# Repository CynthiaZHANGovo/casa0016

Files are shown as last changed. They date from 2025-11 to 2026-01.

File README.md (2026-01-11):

# Study Assistant

The **Study Assistant** is a smart, sensor-driven desktop companion designed to improve study efficiency and encourage healthier learning habits. It monitors brightness, noise, distance, and user presence, then provides real-time feedback through an RGB LCD and multi-color LED indicators.

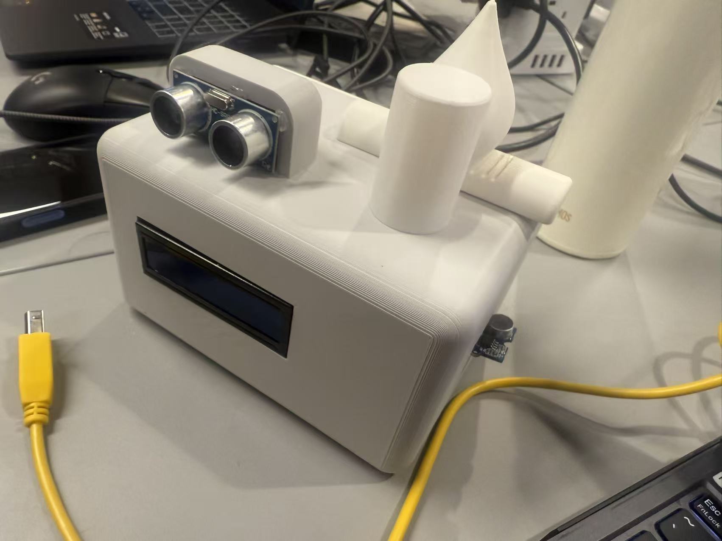
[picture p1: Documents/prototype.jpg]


---

## 📌 Overview

The Study Assistant integrates several sensors, a dynamic feedback system, and a custom 3D-printed enclosure. It automatically tracks focus time, recommends study durations, and enforces rest intervals based on environmental quality.

### Core Capabilities

* Real-time environmental monitoring (lux + noise)
* Ultrasonic-based presence and distance measurement
* Dynamic recommended study duration
* Dynamic rest duration
* Automatic environment light control
* Multi-state LED status feedback
* LCD dual-page interface
* Smart Rest Mode with power saving
* Refined behavior when distance is invalid (LEDs turn off unless noisy)

---

## ✨ Key Features

### 🎯 Smart Focus Tracking

* Detects when the user is present
* Measures:

  * Current study session duration
  * Total accumulated study time
* Continuously compares time against automatically calculated recommendations

### 😴 Intelligent Rest Mode

Triggered when continuous study exceeds recommended duration.

During Rest Mode:

* Status LEDs locked to **red**
* Environment LEDs **off**
* LCD shows:

  * `Rest: <elapsed> / <required> m`
  * `Leave desk...`
* After required rest time: system enters **Rest Finished** state

  * Status LEDs turn **orange** until the user returns

### 🔄 Updated LED Behavior

Latest logic:

* **Green** — user present & environment normal
* **Blue** — user too close
* **Yellow** — environment too noisy
* **Red** — rest required
* **Orange** — rest finished (waiting for user)
* **No Delay** — LED color now updates instantly
* **Invalid distance** — *LED stays off unless noise is high*

### 📟 LCD Dual-Page System

When not resting, the LCD alternates every 2 seconds:

**Page 0 — Study Progress**

```
Total: <minutes>
(<current> / Rec:<recommended>)
```

**Page 1 — Environment**

```
Lux: <value>
Noise: <value>
```

---

## 🧠 Sensor Logic Summary

| Sensor | Purpose | Usage |
| --- | --- | --- |
| HC-SR04 | Distance & presence | posture, presence, rest logic |
| VEML7700 | Brightness | environment quality, rest & study tuning, auto light control |
| Analog microphone | Noise | environment quality, LED feedback |
| millis() | Timing | non-blocking session & rest tracking |

Both study and rest durations adapt dynamically to environmental conditions.

---

# 🖼️ Design Documents (in `/Documents/`)

All design drawings, early concept sketches, electronics documentation, and PCB design files are stored in:

/Documents/

These materials illustrate the full development process from concept → electronic design → PCB layout.

---

## ✏️ Concept Sketch

The initial sketch visualizes the first idea of the Study Assistant, including enclosure proportion, sensor placement, and user-facing interactions.

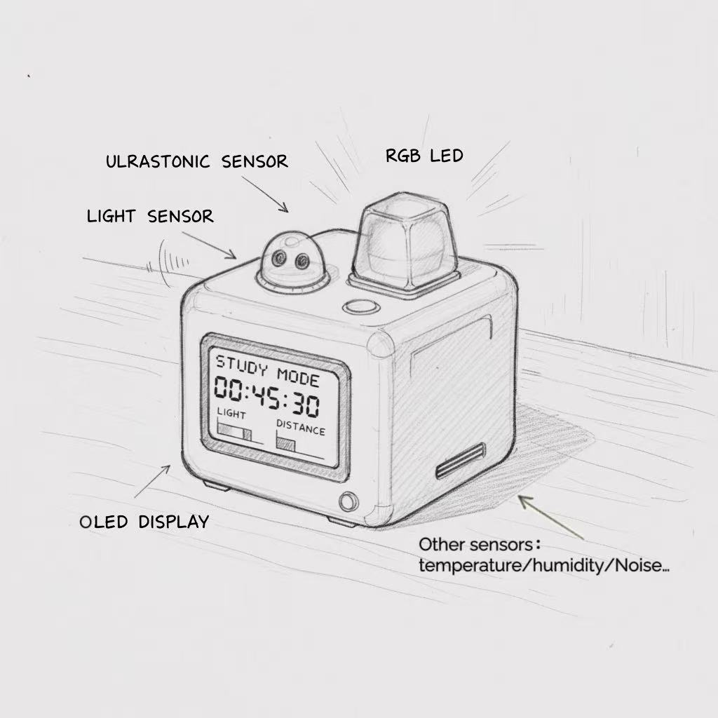
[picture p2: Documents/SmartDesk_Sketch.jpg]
Concept Sketch


---

## 🧩 Schematic Diagram

The schematic documents all circuit connections including the ultrasonic sensor, VEML7700 brightness sensor, microphone input, I2C LCD, and indicator LEDs.
**Designed in Tinkercad.**

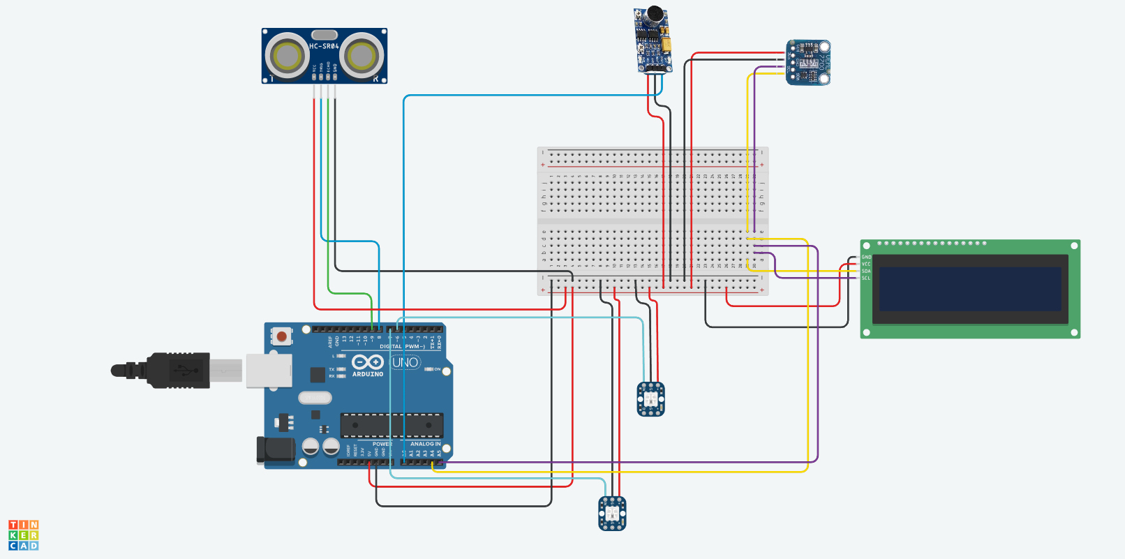
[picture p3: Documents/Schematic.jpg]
Schematic


---

## 🟩 PCB Layout

The PCB layout converts the schematic into a manufacturable and compact board designed to fit inside the 3D printed shell.
**Designed in Tinkercad.**

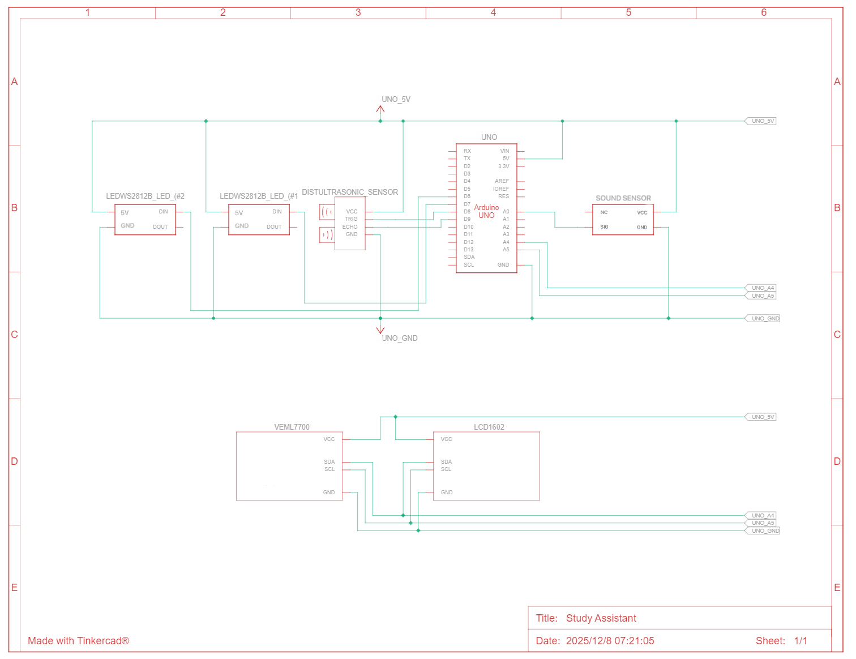
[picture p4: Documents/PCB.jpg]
PCB Layout


---

# 🛠️ 3D Printed Shell (from `/Shell/`)

The Study Assistant enclosure includes a main shell and a detachable top cover.  
Both parts were modelled for 3D printing through *Fusion 360* and designed to house all electronics securely.

---

### 🟦 Shell (Main Body)

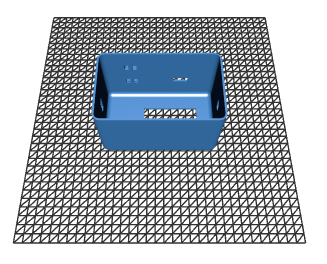
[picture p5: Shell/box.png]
Shell Front Placeholder


**STL download:**  
https://github.com/CynthiaZHANGovo/casa0016/blob/main/Shell/Studybox2.0.stl

---

### 🟧 Shell Cover

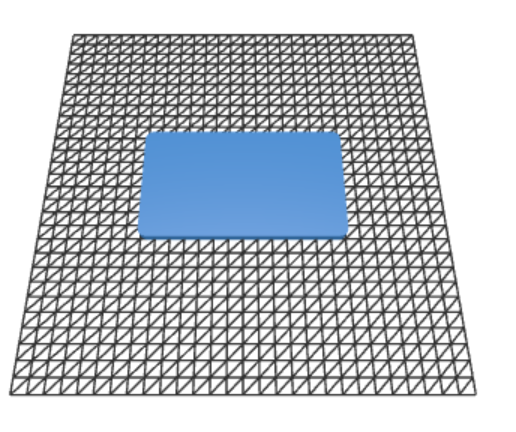
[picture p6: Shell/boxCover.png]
Shell Cover Placeholder


**STL download:**  
https://github.com/CynthiaZHANGovo/casa0016/blob/main/Shell/Study_Box_Cover.stl

---

### 🎃 Additional Decorative Models (Open-source Resources)

These optional decorative elements are sourced from open 3D model libraries and used for aesthetic enhancement:

- **Campfire decoration** — [open-source model](https://makerworld.com.cn/zh/models/672740-gou-huo-deng-mi-ni-ledgou-huo-tai-deng?from=search#profileId-617935)
- **Lamp shade decoration** — [open-source model](https://makerworld.com.cn/zh/models/1686858-fen-wei-deng?from=search#profileId-1854094)
- **Pumpkin lantern decoration** — [open-source model](https://makerworld.com.cn/zh/models/1678338-nan-gua-deng-zhao-zhi-xu-1xiao-shi-da-yin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)

---

## 🎬 Demo Videos

This section demonstrates the Study Assistant in real-world use, including both general functionality and dynamic mode switching behavior.

---

### ▶️ Demo 1 — Full Functionality Overview

Demonstrates the **overall workflow and core features** of the Study Assistant, including:

* Presence detection
* Study time tracking
* Environmental monitoring
* Noise warning
* Distance warning
* LCD dual-page display
* LED status feedback

📺 **Watch video:**
[https://www.youtube.com/watch?v=R-oBgMGgS7g](https://www.youtube.com/watch?v=R-oBgMGgS7g)

Full Function Demo (https://www.youtube.com/watch?v=R-oBgMGgS7g)

### ▶️ Demo 2 — Mode Switching & Status Transitions

Focuses on **different system modes and real-time transitions**, including:

* Normal study mode
* Rest mode activation
* Rest finished state

📺 **Watch video:**
[https://youtu.be/XXJL6YK80Yg](https://youtu.be/XXJL6YK80Yg)

Mode Switching Demo (https://youtu.be/XXJL6YK80Yg)

---

# 💻 Arduino Code (Final Version)

The complete Arduino sketch with all functions, detailed English comments, and structured serial output is located at:

/StudyAssistant

Direct link:  
👉 **[Study_Assistant_Final.ino](StudyAssistant)**

---

# 📂 Repository

Full project available at:  
👉 https://github.com/CynthiaZHANGovo/casa0016

---

# 👩‍💻 Author

**Xinyi Zhang**  Cyn Zhang

GitHub: https://github.com/CynthiaZHANGovo  
UCL CASA0016

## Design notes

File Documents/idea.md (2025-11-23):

# **"Focused Study Feedback Station"**

A small desk device for combined monitoring and adjustment of **time + environment** while you are studying at your desk (light & temperature adjustment, distance reminders, and smart break prompts).

---

### 1. Ultrasonic Distance Sensor

- Detects whether you are sitting at the desk, to record **effective study time**.

- Measures how far you are from the screen, to trigger **“too close” distance reminders**.

### 2. Light Sensor

- Measures ambient/desk brightness (you should at least have the light on when studying).

- When the environment is too dark, it can automatically turn on a lamp or remind you to switch it on.

### 3. (Optional) Noise + Temperature / Humidity

- **Noise**: checks whether the study environment is too noisy.

- **Temperature / Humidity**: checks if the room is too hot, cold, or stuffy.

- These act as additional indicators of overall environment quality.

---

### Logic

- The system only starts recording when it detects that **you are present** at the desk.

- It records your **daily effective study time** and, during those periods, logs the corresponding environment data.

- Based on brightness, temperature, noise level, and distance while you are seated, it produces an **environment quality feedback** for your study sessions.

---

### Real-time Display

- `Today’s focused time: X minutes`

- `Environment: brightness XX, temperature XX, noise XX (optional)`

- `Distance: XX cm (too close / OK)`

---

### Feedback Channels

- **OLED screen**: shows focused time, environment readings, and textual warnings or tips.

- **RGB LED**:

  - Green: you are present and the environment is generally OK.

  - Yellow: minor issues (slightly dark, slightly noisy, etc.).

  - Red: clear problems (too dark, too noisy, or too close to the screen).

---

### “Time to Take a Break” Reminder (Not Just Time-Based)

- The system does **not** trigger breaks based only on “you have sat for N minutes”.

- Instead, it combines:

  1.  You have been in a continuous focused session for a relatively long period (e.g. > 30–45 minutes), **and**

  2.  Your environment or posture starts to degrade:

      - brightness getting too low,

      - temperature drifting to an uncomfortable range,

      - noise level increasing, or

      - you are sitting increasingly close to the screen.

- Only when **“long enough focus time” + “worsening environment/behavior”** happen together, the system triggers a **“time to take a break”** reminder (via OLED message + RGB LED change).

This way, the “time’s up” signal is not just a simple timer, but a **combined decision based on time, environment data, and your sitting behavior**.

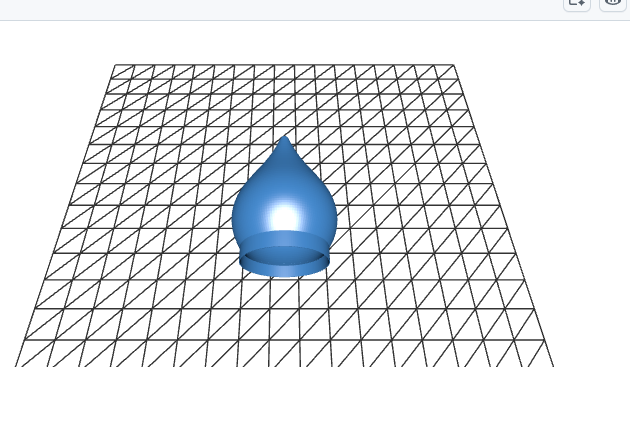
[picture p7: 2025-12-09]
Shell/outer.png

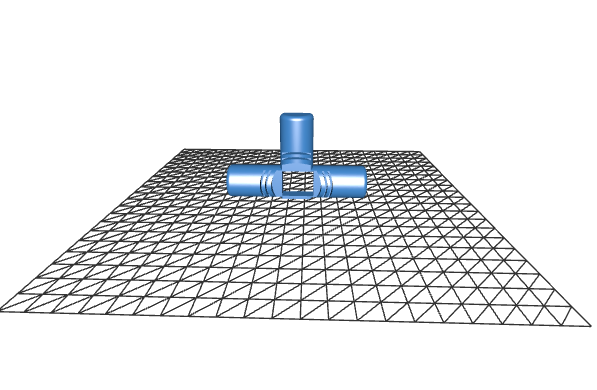
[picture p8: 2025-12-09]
Shell/new logs.png

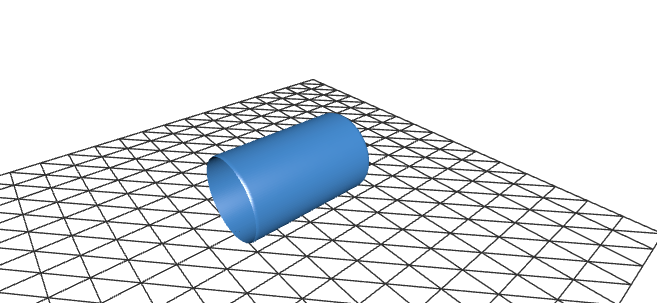
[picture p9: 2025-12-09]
Shell/stimmungslicht.png

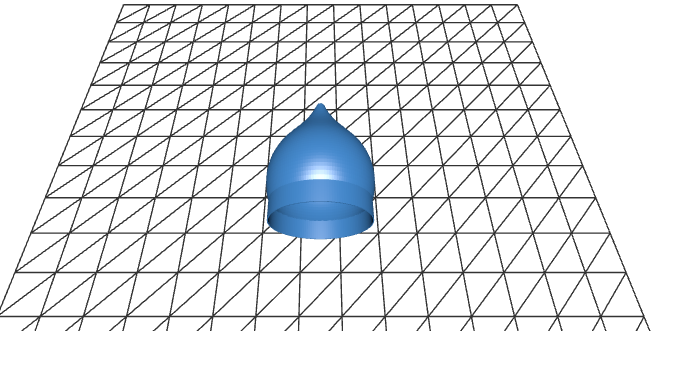
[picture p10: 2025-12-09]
Shell/inner.png

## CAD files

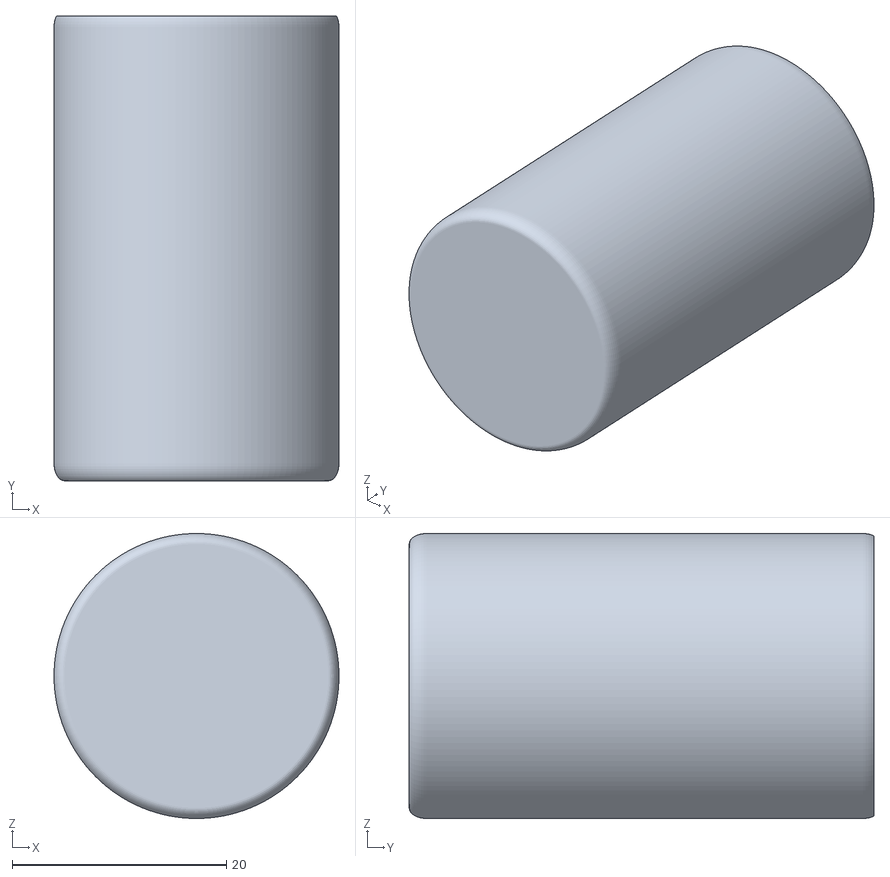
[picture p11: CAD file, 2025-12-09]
Shell/Stimmungslicht.stl
26.6 x 43.4 x 26.6

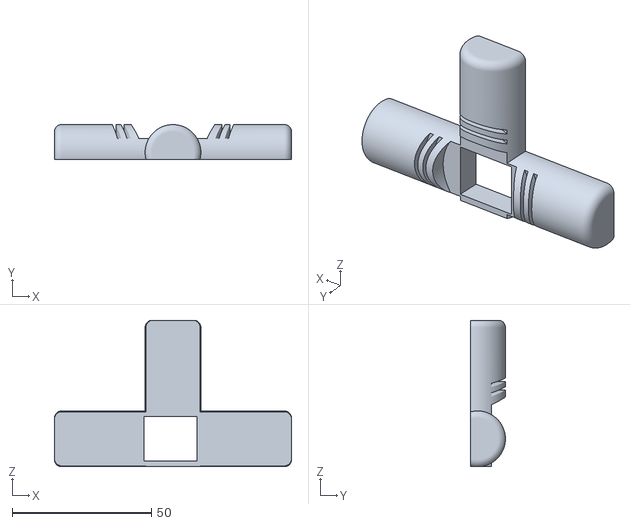
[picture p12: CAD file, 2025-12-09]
Shell/new logs.stl
85.0 x 12.5 x 52.5

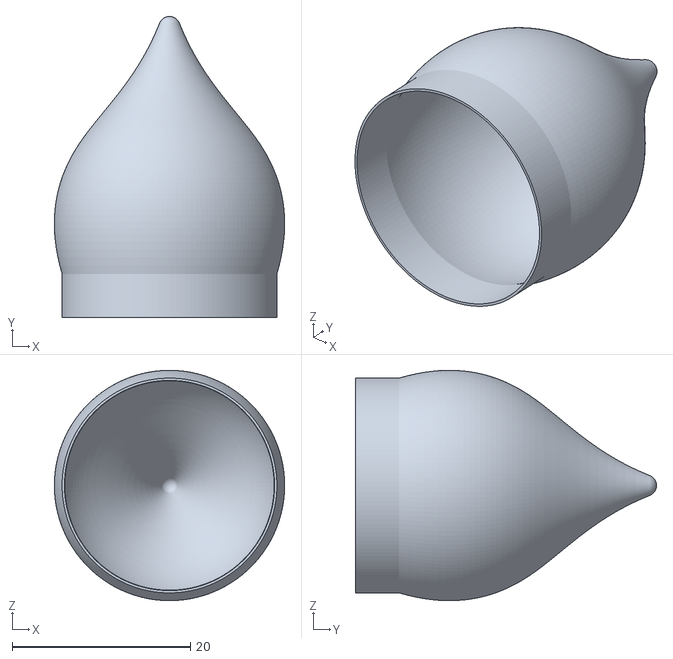
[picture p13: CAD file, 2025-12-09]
Shell/inner.stl
25.9 x 33.8 x 25.9

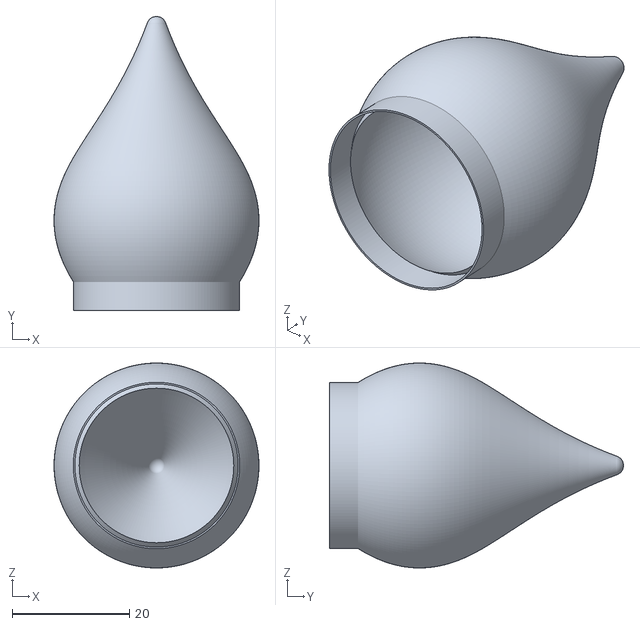
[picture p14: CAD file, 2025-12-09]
Shell/outer.stl
35.0 x 50.1 x 35.0

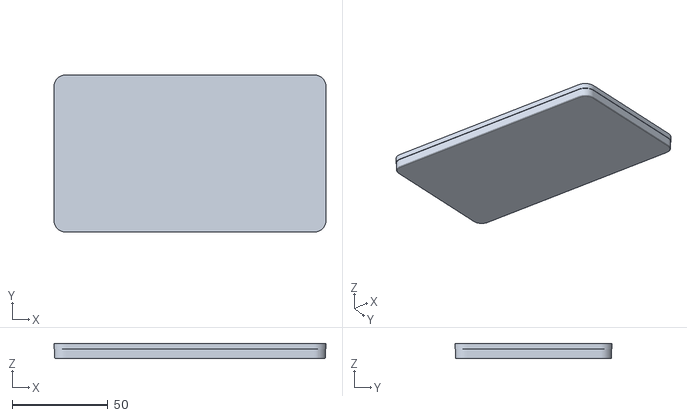
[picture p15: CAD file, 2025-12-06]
Shell/Study_Box_Cover.stl
142.0 x 82.0 x 8.00

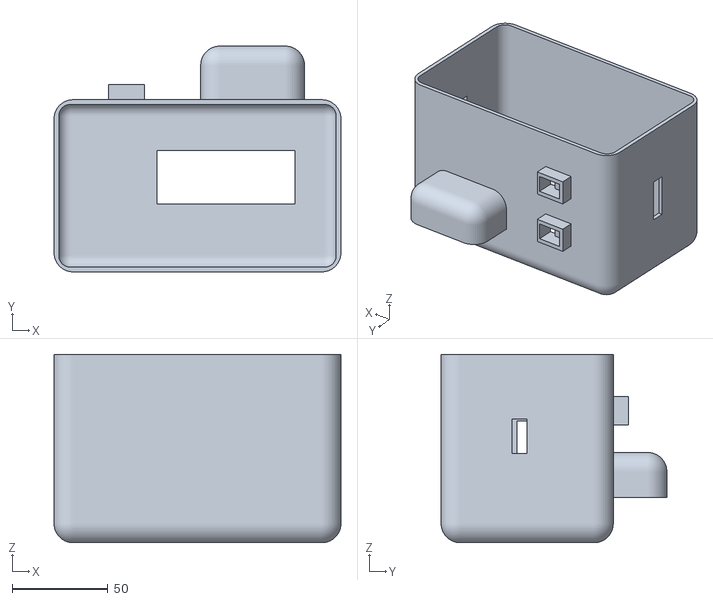
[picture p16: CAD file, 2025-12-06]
Shell/Studybox2.0.stl
150.0 x 118.0 x 98.5

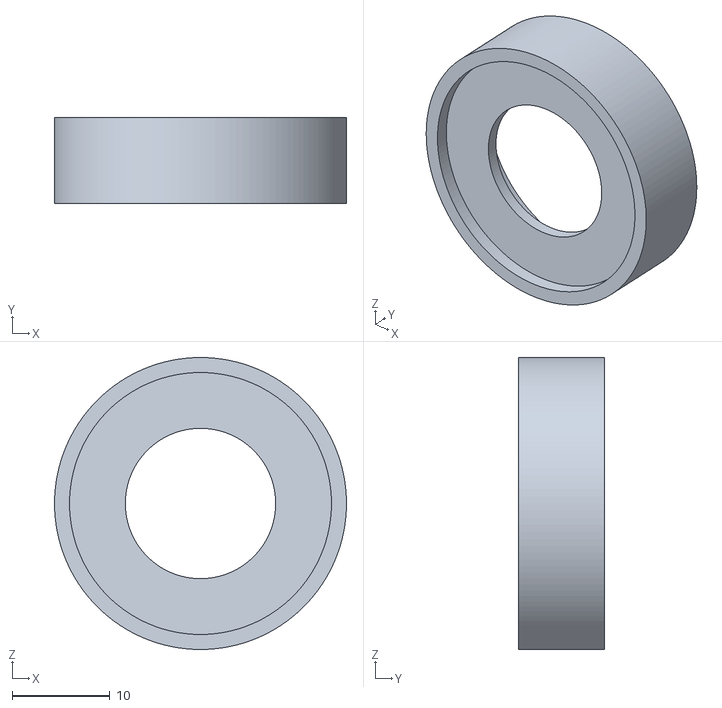
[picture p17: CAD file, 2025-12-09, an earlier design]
Shell/Stimmungslicht (1).stl
29.9 x 8.80 x 29.9

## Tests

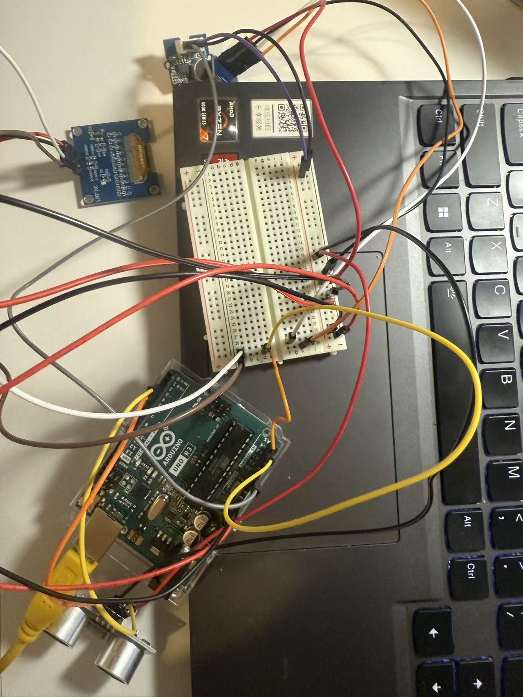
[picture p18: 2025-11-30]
CASA0016_Sensors_Testing/StudyAssistance_Version1.jpg

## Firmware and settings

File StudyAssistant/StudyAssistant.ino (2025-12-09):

// ============================================================================
//  Study Assistant - Focus & Rest System (Final Version, English)
//  Features:
//   - Dynamic recommended focus time based on environment
//   - Dynamic rest time (longer rest for worse environment)
//   - Warning stage before real rest mode
//   - Distance / noise / light monitoring
//   - Auto environment LED control
//   - LCD page switching
//
//  NOTE:
//  This version includes the corrected logic:
//     Worse light or louder noise → SHORTER study time, LONGER rest time
//
//  Serial debug output remains identical to earlier versions.
// ============================================================================

#include <Wire.h>
#include <Adafruit_VEML7700.h>
#include <Adafruit_NeoPixel.h>
#include "rgb_lcd.h"

// ------------------------ PIN DEFINITIONS -----------------------------------
#define TRIG_PIN 9
#define ECHO_PIN 8
#define SOUND_PIN A0
#define ENV_LED_PIN 6
#define STATUS_LED_PIN 7
#define ENV_LED_COUNT 8
#define STATUS_LED_COUNT 8

// ------------------------ OBJECTS -------------------------------------------
Adafruit_VEML7700 veml;
Adafruit_NeoPixel envStrip(ENV_LED_COUNT, ENV_LED_PIN, NEO_GRB + NEO_KHZ800);
Adafruit_NeoPixel statusStrip(STATUS_LED_COUNT, STATUS_LED_PIN, NEO_GRB + NEO_KHZ800);
rgb_lcd lcd;

// ------------------------ THRESHOLDS ----------------------------------------
int PRESENT_DISTANCE = 80;
int TOO_CLOSE_DISTANCE = 20;
int MIN_LUX = 80;
int MAX_NOISE = 300;

// ------------------------ TIMING VARIABLES ----------------------------------
unsigned long recommendedFocusTime = 45UL * 60UL * 1000UL;  
unsigned long dynamicRestTime      = 15UL * 60UL * 1000UL;  

unsigned long focusStartTime = 0;
unsigned long totalFocusTime = 0;
unsigned long restStartTime = 0;
unsigned long absenceStartTime = 0;

// ------------------------ STATE FLAGS ---------------------------------------
bool isPresent = false;
bool inRestMode = false;
bool restFinished = false;
bool waitingForUserToLeave = false;   // new: break warning state

// ------------------------ LCD PAGE CONTROL ----------------------------------
unsigned long lastLcdUpdate = 0;
int lcdPage = 0;

// ------------------------ LED OPTIMIZATION ----------------------------------
int lastR = -1, lastG = -1, lastB = -1;

// ============================================================================
// Helper: Set status LED color only when needed
// ============================================================================
void safeSetStatusColor(int r, int g, int b) {
  if (r == lastR && g == lastG && b == lastB) return;

  for (int i = 0; i < STATUS_LED_COUNT; i++)
    statusStrip.setPixelColor(i, statusStrip.Color(r, g, b));

  statusStrip.show();

  lastR = r;
  lastG = g;
  lastB = b;
}

// ============================================================================
// Ultrasonic distance measurement
// ============================================================================
long getDistanceCM() {
  digitalWrite(TRIG_PIN, LOW);
  delayMicroseconds(2);
  digitalWrite(TRIG_PIN, HIGH);
  delayMicroseconds(10);
  digitalWrite(TRIG_PIN, LOW);

  long duration = pulseIn(ECHO_PIN, HIGH, 30000);
  if (duration == 0) return 0;

  return duration * 0.034 / 2;
}

// ============================================================================
// Environment LED control
// ============================================================================
void setEnvironmentLight(bool on) {
  for (int i = 0; i < ENV_LED_COUNT; i++) {
    if (on) envStrip.setPixelColor(i, envStrip.Color(40, 40, 40));
    else    envStrip.setPixelColor(i, 0);
  }
  envStrip.show();
}

// ============================================================================
// Recommended Focus Time (Modified Logic)
// Worse light or louder noise → shorter study time
// ============================================================================
void calculateRecommendedTime(float lux, int noise, long distanceCM) {
  int baseMin = 45;
  int delta = 0;

  // Light logic: dim → study shorter
  if (lux >= 300) delta += 5;         // bright → slightly longer session
  else if (lux >= 150) delta += 0;    // normal
  else if (lux < 80) delta -= 10;     // too dim → shorter recommended session

  // Noise logic: loud → study shorter
  if (noise < 200) delta += 5;        // quiet → slightly longer
  else if (noise < 350) delta += 0;   // moderate
  else if (noise > 650) delta -= 10;  // very loud → shorter study time

  // Distance logic: too close → study shorter
  if (distanceCM >= 40) delta += 5;  
  else if (distanceCM < 20 && distanceCM > 0) delta -= 5;

  int recMin = baseMin + delta;

  if (recMin < 20) recMin = 20;
  if (recMin > 60) recMin = 60;

  recommendedFocusTime = recMin * 60000UL;
}

// ============================================================================
// Dynamic Rest Time (Modified Logic)
// Worse environment → longer rest
// ============================================================================
void calculateRestTime(float lux, int noise) {
  int baseMin = 15;
  int delta = 0;

  if (lux < 80) delta += 5;       // dim → more rest
  if (noise > 650) delta += 5;    // loud → more rest

  if (lux > 150 && noise < 250)   // good environment → less rest
    delta -= 5;

  int restMin = baseMin + delta;

  if (restMin < 5) restMin = 5;
  if (restMin > 25) restMin = 25;

  dynamicRestTime = restMin * 60000UL;
}

// ============================================================================
// Setup
// ============================================================================
void setup() {
  pinMode(TRIG_PIN, OUTPUT);
  pinMode(ECHO_PIN, INPUT);
  Serial.begin(9600);

  envStrip.begin();
  statusStrip.begin();

  lcd.begin(16, 2);
  lcd.setRGB(0, 40, 0);
  lcd.clear();
  lcd.print("System Ready");
  delay(1500);
  lcd.clear();

  if (!veml.begin()) {
    lcd.print("VEML ERROR");
    while (1);
  }
}

// ============================================================================
// Main Loop
// ============================================================================
void loop() {

  long distance = getDistanceCM();
  int noiseVal  = analogRead(SOUND_PIN);
  float lux     = veml.readLux();

  bool validDistance = (distance > 5 && distance < 200);
  bool userNear      = validDistance && (distance < PRESENT_DISTANCE);
  bool userTooClose  = validDistance && (distance < TOO_CLOSE_DISTANCE);

  calculateRecommendedTime(lux, noiseVal, validDistance ? distance : 999);
  calculateRestTime(lux, noiseVal);

  // ========================================================================
  // 1) BREAK WARNING STATE (user must leave for 2 sec)
  // ========================================================================
  if (waitingForUserToLeave) {

    safeSetStatusColor(40, 0, 0);
    lcd.setRGB(40, 0, 0);

    lcd.clear();
    lcd.setCursor(0, 0);
    lcd.print("Time for break!");

    if (userNear) {
      absenceStartTime = millis();
    }

    if (!userNear && (millis() - absenceStartTime >= 2000)) {
      waitingForUserToLeave = false;
      inRestMode = true;
      restStartTime = millis();
    }

    delay(250);
    return;
  }

  // ========================================================================
  // 2) REAL REST MODE
  // ========================================================================
  if (inRestMode) {

    safeSetStatusColor(40, 0, 0);
    setEnvironmentLight(false);

    unsigned long restElapsed = millis() - restStartTime;

    lcd.setRGB(40, 0, 0);
    lcd.clear();
    lcd.setCursor(0, 0);
    lcd.print("Rest:");
    lcd.print(restElapsed / 60000UL);
    lcd.print("/");
    lcd.print(dynamicRestTime / 60000UL);
    lcd.print("m");

    lcd.setCursor(0, 1);
    lcd.print("Leave desk...");

    if (!userNear && restElapsed >= dynamicRestTime) {
      inRestMode = false;
      restFinished = true;
      safeSetStatusColor(20, 20, 0);
    }

    delay(250);
    return;
  }

  // ========================================================================
  // 3) NORMAL FOCUS MODE
  // ========================================================================
  if (userNear && !isPresent) {
    isPresent = true;
    restFinished = false;
    focusStartTime = millis();
  }

  if (!userNear && isPresent) {
    totalFocusTime += millis() - focusStartTime;
    isPresent = false;
  }

  unsigned long currentFocus = isPresent ? millis() - focusStartTime : 0;
  unsigned long todayFocus   = totalFocusTime + currentFocus;

  // Enter WARNING state
  if (!inRestMode && isPresent && currentFocus >= recommendedFocusTime) {
    totalFocusTime += currentFocus;
    isPresent = false;

    waitingForUserToLeave = true;
    absenceStartTime = millis();
    safeSetStatusColor(40, 0, 0);
    return;
  }

  // ========================================================================
  // After rest finished: wait for user return
  // ========================================================================
  if (restFinished) {
    setEnvironmentLight(false);
    safeSetStatusColor(20, 20, 0);

    if (userNear) {
      restFinished = false;
      focusStartTime = millis();
    }
  }

  // ========================================================================
  // STATUS LED + LCD COLOR
  // ========================================================================
  if (isPresent) {
    if (!validDistance) {
      if (noiseVal > MAX_NOISE) {
        safeSetStatusColor(40, 40, 0);
        lcd.setRGB(40, 40, 0);
      } else {
        safeSetStatusColor(0, 0, 0);
        lcd.setRGB(0, 0, 0);
      }
    }
    else if (userTooClose) {
      safeSetStatusColor(0, 0, 40);
      lcd.setRGB(0, 0, 40);
    }
    else if (noiseVal > MAX_NOISE) {
      safeSetStatusColor(40, 40, 0);
      lcd.setRGB(40, 40, 0);
    }
    else {
      safeSetStatusColor(0, 40, 0);
      lcd.setRGB(0, 40, 0);
    }
  }

  setEnvironmentLight(lux < MIN_LUX);

  // ========================================================================
  // LCD rotation every 2 sec
  // ========================================================================
  if (millis() - lastLcdUpdate > 2000) {
    lastLcdUpdate = millis();
    lcdPage = (lcdPage + 1) % 2;
    lcd.clear();
  }

  if (lcdPage == 0) {
    lcd.setCursor(0, 0);
    lcd.print("Total:");
    lcd.print(todayFocus / 60000UL);
    lcd.print("m");

    lcd.setCursor(0, 1);
    lcd.print("(");
    lcd.print(currentFocus / 60000UL);
    lcd.print(" / Rec:");
    lcd.print(recommendedFocusTime / 60000UL);
    lcd.print(")");
  }
  else {
    lcd.setCursor(0, 0);
    lcd.print("Lux:");
    lcd.print((int)lux);

    lcd.setCursor(0, 1);
    lcd.print("Noise:");
    lcd.print(noiseVal);
  }

  // ========================================================================
  // FULL SERIAL DEBUG OUTPUT (unchanged)
  // ========================================================================
  Serial.println("================ SENSOR DEBUG ================");
  Serial.print("Distance(cm): "); Serial.println(distance);
  Serial.print("ValidDistance: "); Serial.println(validDistance ? "YES" : "NO");
  Serial.print("Lux: "); Serial.println(lux);
  Serial.print("Noise: "); Serial.println(noiseVal);
  Serial.print("UserPresent: "); Serial.println(isPresent ? "YES" : "NO");
  Serial.print("CurrentFocus(ms): "); Serial.println(currentFocus);
  Serial.print("TotalFocus(ms): "); Serial.println(todayFocus);
  Serial.print("RecommendedFocus(ms): "); Serial.println(recommendedFocusTime);
  Serial.print("RestMode: "); Serial.println(inRestMode ? "YES" : "NO");
  Serial.print("WaitingLeave: "); Serial.println(waitingForUserToLeave ? "YES" : "NO");
  Serial.print("RestFinished: "); Serial.println(restFinished ? "YES" : "NO");
  Serial.print("LED(R,G,B): ");
  Serial.print(lastR); Serial.print(",");
  Serial.print(lastG); Serial.print(",");
  Serial.println(lastB);
  Serial.println("----------------------------------------------");

  delay(200);
}

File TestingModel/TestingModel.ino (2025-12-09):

// ----- DEMO VERSION -----
// Fixed focus time = 1 minute
// Fixed rest time = 1 minute
// Sensors only influence LEDs and LCD, NOT timing
// Rest mode now requires 2 seconds of no user after red warning
// ----------------------------------------------

#include <Wire.h>
#include <Adafruit_VEML7700.h>
#include <Adafruit_NeoPixel.h>
#include "rgb_lcd.h"

#define TRIG_PIN 9
#define ECHO_PIN 8
#define SOUND_PIN A0
#define ENV_LED_PIN 6
#define STATUS_LED_PIN 7
#define ENV_LED_COUNT 8
#define STATUS_LED_COUNT 8

Adafruit_VEML7700 veml;
Adafruit_NeoPixel envStrip(ENV_LED_COUNT, ENV_LED_PIN, NEO_GRB + NEO_KHZ800);
Adafruit_NeoPixel statusStrip(STATUS_LED_COUNT, STATUS_LED_PIN, NEO_GRB + NEO_KHZ800);
rgb_lcd lcd;

// Fixed demo times
unsigned long FIXED_FOCUS_TIME = 1UL * 60UL * 1000UL;  
unsigned long FIXED_REST_TIME  = 1UL * 60UL * 1000UL;

bool isPresent = false;
bool inRestMode = false;
bool waitingForUserToLeave = false;

unsigned long focusStartTime = 0;
unsigned long restStartTime = 0;
unsigned long absenceStartTime = 0;

int MIN_LUX = 80;
int MAX_NOISE = 300;
int PRESENT_DISTANCE = 80;
int TOO_CLOSE_DISTANCE = 20;

// -------------------------------- LED HELPERS -----------------------------------

void safeSetStatusColor(int r, int g, int b) {
  for (int i = 0; i < STATUS_LED_COUNT; i++)
    statusStrip.setPixelColor(i, statusStrip.Color(r, g, b));
  statusStrip.show();
}

void setEnvironmentLight(bool state) {
  for (int i = 0; i < ENV_LED_COUNT; i++) {
    if (state) envStrip.setPixelColor(i, envStrip.Color(40, 40, 40));
    else envStrip.setPixelColor(i, 0);
  }
  envStrip.show();
}

// -------------------------------- SENSOR FUNCTIONS -----------------------------------

long getDistanceCM() {
  digitalWrite(TRIG_PIN, LOW);
  delayMicroseconds(2);
  digitalWrite(TRIG_PIN, HIGH);
  delayMicroseconds(10);
  digitalWrite(TRIG_PIN, LOW);

  long duration = pulseIn(ECHO_PIN, HIGH, 30000);
  if (duration == 0) return 0;
  return duration * 0.034 / 2;
}

// -------------------------------- SETUP -----------------------------------

void setup() {
  pinMode(TRIG_PIN, OUTPUT);
  pinMode(ECHO_PIN, INPUT);
  Serial.begin(9600);

  envStrip.begin();
  statusStrip.begin();

  lcd.begin(16, 2);
  lcd.setRGB(0, 40, 0);
  lcd.clear();
  lcd.print("DEMO Mode Ready");
  delay(1500);
  lcd.clear();

  if (!veml.begin()) {
    lcd.print("VEML ERROR");
    while (1);
  }
}

// -------------------------------- MAIN LOOP -----------------------------------

void loop() {

  long distance = getDistanceCM();
  int noiseVal = analogRead(SOUND_PIN);
  float lux = veml.readLux();

  bool validDistance = (distance > 5 && distance < 200);
  bool userNear = validDistance && (distance < PRESENT_DISTANCE);
  bool userTooClose = validDistance && (distance < TOO_CLOSE_DISTANCE);

  // ======================================================================
  // ------------------------- REST MODE ----------------------------------
  // ======================================================================
  if (inRestMode) {
    safeSetStatusColor(40, 0, 0);   // Red
    setEnvironmentLight(false);

    lcd.setRGB(40, 0, 0);
    lcd.clear();
    lcd.setCursor(0, 0);
    lcd.print("Resting...");

    unsigned long elapsed = millis() - restStartTime;
    lcd.setCursor(0, 1);
    lcd.print(elapsed / 1000);
    lcd.print(" / 60 s");

    if (!userNear && elapsed >= FIXED_REST_TIME) {
      inRestMode = false;
      safeSetStatusColor(0, 40, 0);  // Green again
      lcd.setRGB(0, 40, 0);
    }
    delay(300);
    return;
  }

  // ======================================================================
  // ---------------- WAITING FOR USER TO LEAVE (RED WARNING) -------------
  // ======================================================================
  if (waitingForUserToLeave) {
    safeSetStatusColor(40, 0, 0); // red warning
    setEnvironmentLight(false);

    lcd.setRGB(40, 0, 0);
    lcd.clear();
    lcd.setCursor(0, 0);
    lcd.print("Time for a break!");

    // User is still present → reset clock
    if (userNear) {
      absenceStartTime = millis();
    }

    // User left for 2 seconds → enter rest mode
    if (!userNear && millis() - absenceStartTime >= 2000) {
      waitingForUserToLeave = false;
      inRestMode = true;
      restStartTime = millis();
    }

    delay(300);
    return;
  }

  // ======================================================================
  // ---------------------------- FOCUS MODE -------------------------------
  // ======================================================================
  if (userNear && !isPresent) {
    isPresent = true;
    focusStartTime = millis();
  }
  if (!userNear && isPresent) {
    isPresent = false;
  }

  unsigned long currentFocus = isPresent ? millis() - focusStartTime : 0;

  // Reached 1-minute focus → red warning (NOT rest yet)
  if (isPresent && currentFocus >= FIXED_FOCUS_TIME) {
    waitingForUserToLeave = true;
    absenceStartTime = millis();  // Start tracking absence
    safeSetStatusColor(40, 0, 0); // red
    return;
  }

  // LED + LCD based on sensors
  if (!validDistance) {
    safeSetStatusColor(0, 0, 0);
    lcd.setRGB(0, 0, 0);
  }
  else if (userTooClose) {
    safeSetStatusColor(0, 0, 40);   // Blue
    lcd.setRGB(0, 0, 40);
  }
  else if (noiseVal > MAX_NOISE) {
    safeSetStatusColor(40, 40, 0);  // Yellow
    lcd.setRGB(40, 40, 0);
  }
  else {
    safeSetStatusColor(0, 40, 0);   // Green
    lcd.setRGB(0, 40, 0);
  }

  setEnvironmentLight(lux < MIN_LUX);

  // LCD in focus mode
  lcd.clear();
  lcd.setCursor(0, 0);
  lcd.print("Focus:");
  lcd.print(currentFocus / 1000);
  lcd.print("s");

  lcd.setCursor(0, 1);
  lcd.print("Lux:");
  lcd.print((int)lux);
  lcd.print("  N:");
  lcd.print(noiseVal);

  delay(300);
}

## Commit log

2025-11-30 Add Tests of sensors
    Integrated and tested UNO with XFP1116-07AY OLED, VEML7700 light sensor, HC-SR04, Sound Sensor v1.6, and WS2812B; all modules read successfully and displayed data on OLED and Serial.
2025-12-06 Add the shell
    [Study_Box_Cover.stl, Studybox2.0.stl]
2025-12-08 Add PCB and Schematic of the prototype
2025-12-09 Revise README for Study Assistant project
    Updated the README to provide a comprehensive overview of the Study Assistant project, including features, sensor logic, design documents, and links to the Arduino code.
2025-12-09 Add decorations
    [Stimmungslicht (1).stl, Stimmungslicht.stl, inner.stl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]
2025-12-09 Fix links to Arduino code in README
    Updated links and directory structure in README.
